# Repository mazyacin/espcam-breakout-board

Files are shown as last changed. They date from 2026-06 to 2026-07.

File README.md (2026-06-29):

# espcam-breakout-board
high-end ESP32-Cam breakout-board for IOT and monetering systems , so there has been a problem with the espcam and its the programming because it does not have a USB to UART converter so i am making a breakout board for it that solves that problem and adds more features like :tp5100 for charging ,MT3608 for 5v,3.3v,output, bme280 for IOT  also an IMU mpu6000 ,BMS( DW01A protection IC with 2 mosfets), 
it supports 4.2v batteries and cells any higher voltage will cut the power because the BMS is for 1s configuration, the charging is at 2A, bme temperature accuracy is ±0.5°C and humidity ±3%  Barometric Pressure ±1.0 hPa its set to i2c and its address is 0x76 or 0x77, mpu6000 is switched to i2c (cs pin is high) and address 0x69 accuracy Gyro: ±250 to ±2000 °/s accelerometer ±2g to ±16g internal tempurature sensor ±1°C

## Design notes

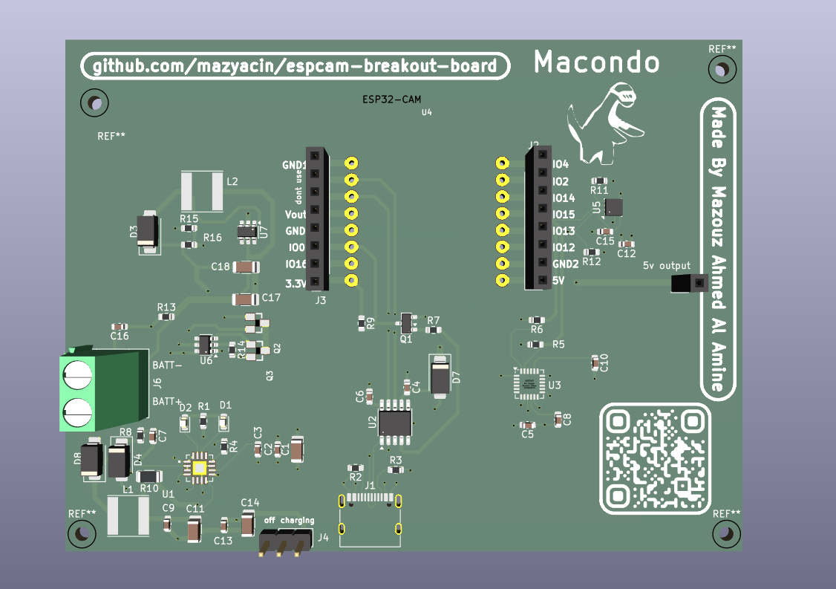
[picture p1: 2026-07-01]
espcam.PNG

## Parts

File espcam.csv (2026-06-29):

Reference | Qty | Value | DNP | Exclude from BOM | Exclude from Board | Footprint | Datasheet | LCSC
C1,C11,C14 | 3 | 10uf 16V |  |  |  | Capacitor_SMD:C_1206_3216Metric
C2,C3,C4,C5,C6,C8,C9,C12,C13,C15,C16 | 11 | 0.1uf 16V |  |  |  | Capacitor_SMD:C_0603_1608Metric
C7 | 1 | 0.1nf 16V |  |  |  | Capacitor_SMD:C_0603_1608Metric
C10 | 1 | 0.02uf 16V |  |  |  | Capacitor_SMD:C_0603_1608Metric
C17,C18 | 2 | 22uf 16v |  |  |  | Capacitor_SMD:C_1206_3216Metric
D1,D2 | 2 | LED |  |  |  | LED_SMD:LED_0603_1608Metric
D3,D4,D7,D8 | 4 | SS34 |  |  |  | Diode_SMD:D_SMA | https://www.vishay.com/docs/88751/ss32.pdf
J1 | 1 | USB_C_Receptacle_USB2.0_16P |  |  |  | Connector_USB:USB_C_Receptacle_G-Switch_GT-USB-7010ASV | https://www.usb.org/sites/default/files/documents/usb_type-c.zip
J2,J3 | 2 | Conn_01x08_Socket |  |  |  | Connector_PinSocket_2.54mm:PinSocket_1x08_P2.54mm_Vertical
J4 | 1 | Conn_01x03_Pin |  |  |  | Connector_PinHeader_2.54mm:PinHeader_1x03_P2.54mm_Vertical
L1 | 1 | 10uh |  |  |  | Inductor_SMD:L_Taiyo-Yuden_NR-60xx
L2 | 1 | 22uh |  |  |  | Inductor_SMD:L_Taiyo-Yuden_NR-60xx
Q1 | 1 | SS8050 |  |  |  | Package_TO_SOT_SMD:SOT-23 | http://www.secosgmbh.com/datasheet/products/SSMPTransistor/SOT-23/SS8050.pdf
Q2,Q3 | 2 | SI2302 |  |  |  | 65161:SOT23
R1,R14 | 2 | 1k ohm |  |  |  | Resistor_SMD:R_0603_1608Metric
R2,R3 | 2 | 5.1k ohm |  |  |  | Resistor_SMD:R_0603_1608Metric
R4 | 1 | 50k ohm |  |  |  | Resistor_SMD:R_0603_1608Metric
R5,R6,R11,R12 | 4 | 4.7k ohm |  |  |  | Resistor_SMD:R_0603_1608Metric
R7,R9 | 2 | 10k ohm |  |  |  | Resistor_SMD:R_0603_1608Metric
R8 | 1 | 3 ohm |  |  |  | Resistor_SMD:R_0603_1608Metric
R10 | 1 | 0.067 Ω |  |  |  | Resistor_SMD:R_1206_3216Metric
R13 | 1 | 100 ohm |  |  |  | Resistor_SMD:R_0603_1608Metric
R15 | 1 | 2.2k ohm |  |  |  | Resistor_SMD:R_0603_1608Metric
R16 | 1 | 16.13k ohm |  |  |  | Resistor_SMD:R_0603_1608Metric
U1 | 1 | TP5100 |  |  |  | TP5100:TP5100 | https://voltiq.ru/datasheets/TP5100-datashhet.pdf | C379389
U2 | 1 | CH340K |  |  |  | Package_SO:SSOP-10-1EP_3.9x4.9mm_P1mm_EP2.1x3.3mm | https://cdn.sparkfun.com/assets/5/0/a/8/5/CH340DS1.PDF | C968586
U3 | 1 | MPU-6000 |  |  |  | Sensor_Motion:InvenSense_QFN-24_4x4mm_P0.5mm | https://invensense.tdk.com/wp-content/uploads/2015/02/MPU-6000-Datasheet1.pdf
U4 | 1 | ESP32-CAM |  |  |  | espcam:ESP32-CAM | https://www.handsontec.com/dataspecs/module/ESP32-CAM.pdf,
U5 | 1 | BME280 |  |  |  | Package_LGA:Bosch_LGA-8_2.5x2.5mm_P0.65mm_ClockwisePinNumbering | https://www.bosch-sensortec.com/media/boschsensortec/downloads/datasheets/bst-bme280-ds002.pdf | C92489
U6 | 1 | DW01A |  |  |  | Package_TO_SOT_SMD:SOT-23-6 | https://hmsemi.com/downfile/DW01A.PDF | C11702
U7 | 1 | MT3608 |  |  |  | Package_TO_SOT_SMD:SOT-23-6 | https://www.olimex.com/Products/Breadboarding/BB-PWR-3608/resources/MT3608.pdf | C83247

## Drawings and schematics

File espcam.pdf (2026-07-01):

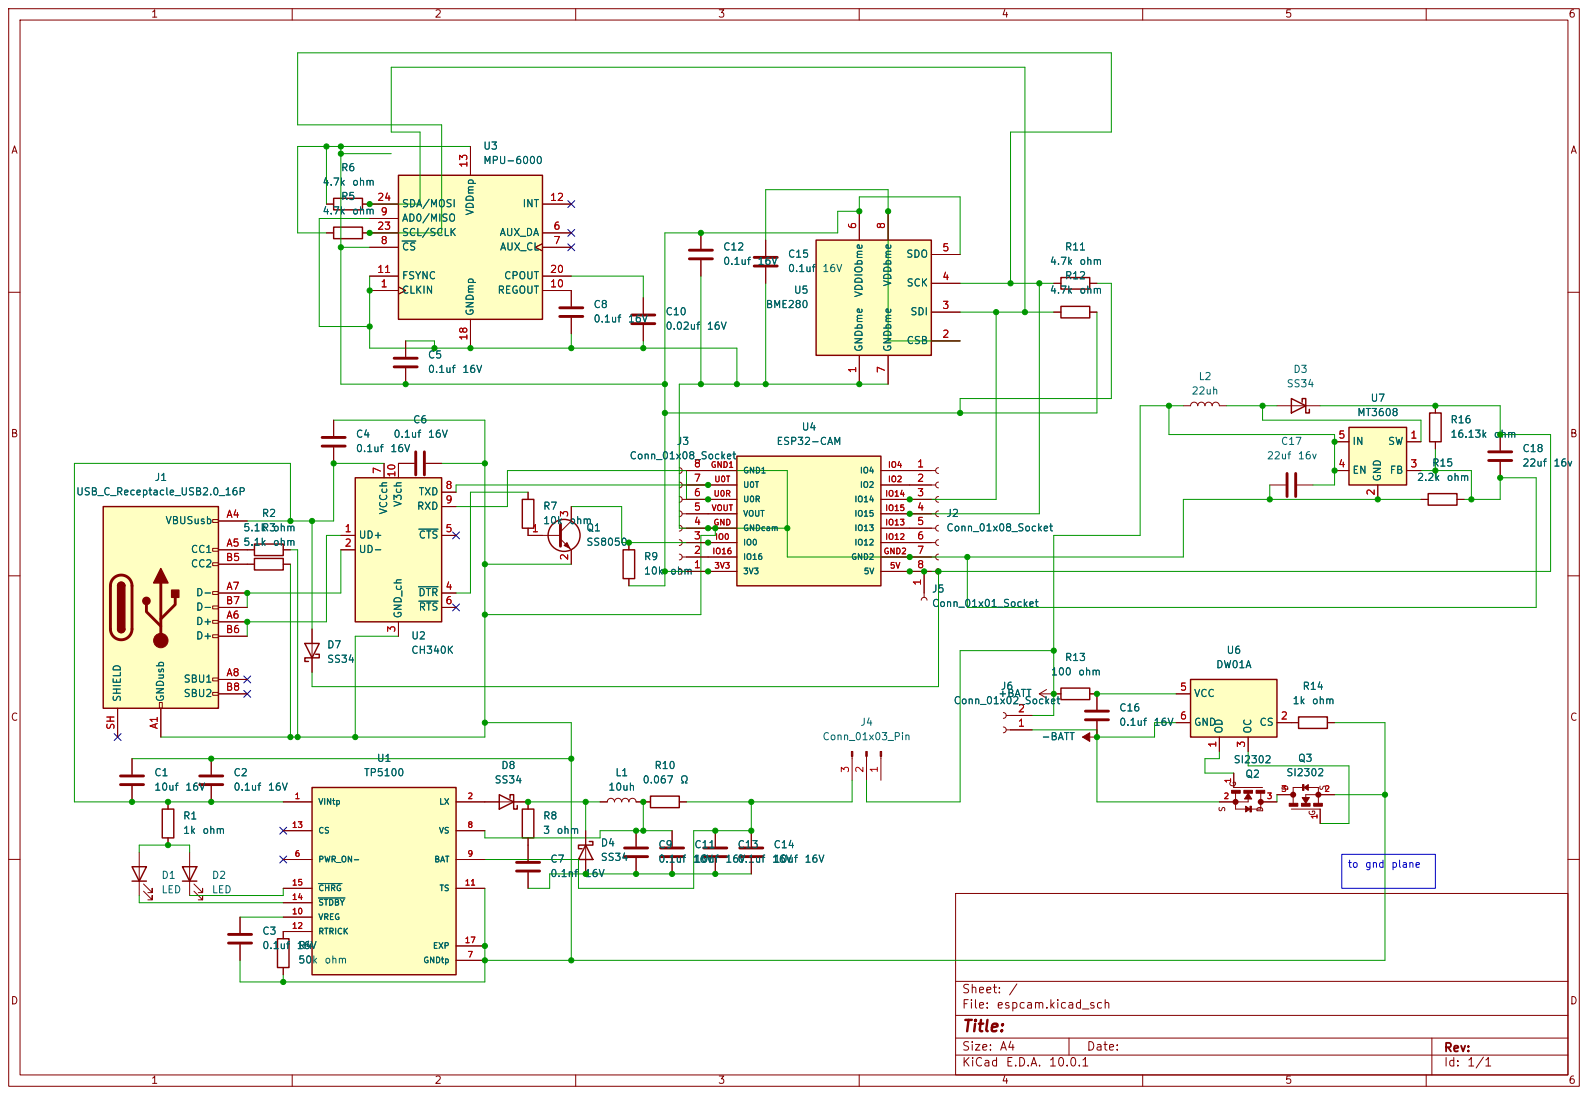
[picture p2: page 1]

J5Conn_01x01_Socket 1 U4

J3 Conn_01x08_Socket ESP32-CAM 1

Size: A4 | Rev:
KiCad E.D.A. 10.0.1 | Id: 1/1

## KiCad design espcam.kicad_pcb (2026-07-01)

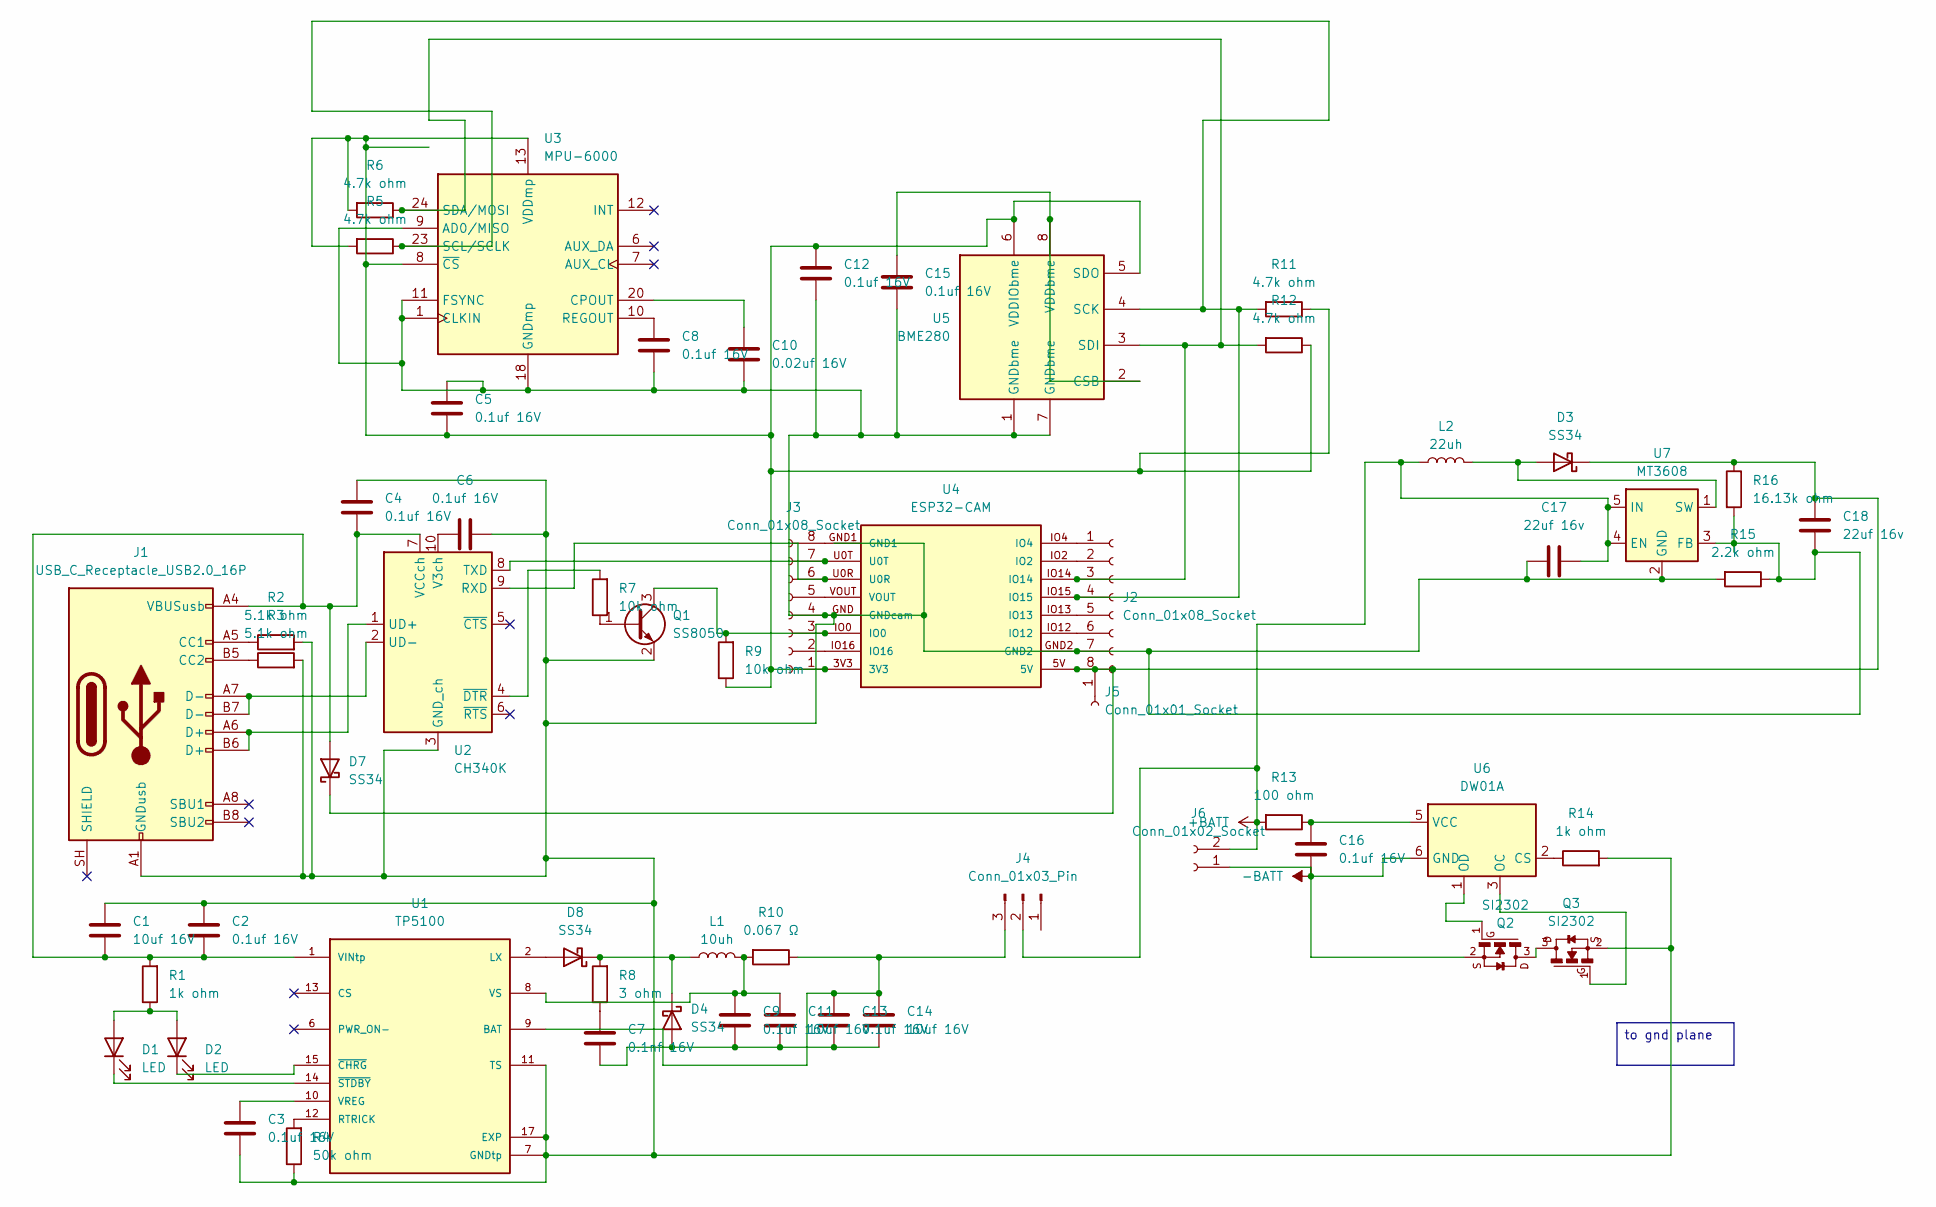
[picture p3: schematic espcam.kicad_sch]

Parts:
C1, C11, C14: 10uf 16V; C_1206_3216Metric
C2, C3, C4, C5, C6, C8, C9, C12, C13, C15, C16: 0.1uf 16V; C_0603_1608Metric
C7: 0.1nf 16V; C_0603_1608Metric
C10: 0.02uf 16V; C_0603_1608Metric
C17, C18: 22uf 16v; C_1206_3216Metric
D1, D2: LED; LED_0603_1608Metric
D3, D4, D7, D8: SS34; D_SMA
J1: USB_C_Receptacle_USB2.0_16P; USB_C_Receptacle_G-Switch_GT-USB-7010ASV
J2, J3: Conn_01x08_Socket; PinSocket_1x08_P2.54mm_Vertical
J4: Conn_01x03_Pin; PinHeader_1x03_P2.54mm_Vertical
J5: Conn_01x01_Socket; PinSocket_1x01_P2.54mm_Vertical
J6: Conn_01x02_Socket; TerminalBlock_Phoenix_MKDS-1,5-2-5.08_1x02_P5.08mm_Horizont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
L1: 10uh; L_Taiyo-Yuden_NR-60xx
L2: 22uh; L_Taiyo-Yuden_NR-60xx
Q1: SS8050; SOT-23
Q2, Q3: SI2302; SOT23
R1, R14: 1k ohm; R_0603_1608Metric
R2, R3: 5.1k ohm; R_0603_1608Metric
R4: 50k ohm; R_0603_1608Metric
R5, R6, R11, R12: 4.7k ohm; R_0603_1608Metric
R7, R9: 10k ohm; R_0603_1608Metric
R8: 3 ohm; R_0603_1608Metric
R10: 0.067 Ω; R_1206_3216Metric
R13: 100 ohm; R_0603_1608Metric
R15: 2.2k ohm; R_0603_1608Metric
R16: 16.13k ohm; R_0603_1608Metric
U1: TP5100; PARTREV 2.3; LCSC C379389
U2: CH340K; SSOP-10-1EP_3.9x4.9mm_P1mm_EP2.1x3.3mm; LCSC C968586
U3: MPU-6000; InvenSense_QFN-24_4x4mm_P0.5mm
U4: ESP32-CAM
U5: BME280; Bosch_LGA-8_2.5x2.5mm_P0.65mm_ClockwisePinNumbering; LCSC C92489
U6: DW01A; SOT-23-6; LCSC C11702
U7: MT3608; SOT-23-6; LCSC C83247

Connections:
+BATT: C17.2, J4.2, J6.2, L2.1, R13.2, U7.4 (EN), U7.5 (IN)
-BATT: C16.2, J6.1, Q2.2, U6.6 (GND)
unnamed: C7.1, R8.1
unnamed: D1.2 (A), D2.2 (A), R1.1
unnamed: D1.1 (K), U1.14 (~STDBY)
unnamed: D2.1 (K), U1.15 (~CHRG)
unnamed: D3.2 (A), L2.2, U7.1 (SW)
unnamed 7: C18.1, D3.1 (K), D7.1 (K), J2.8, J5.1, R16.1, U4.5V; also elsewhere on the board
unnamed: C7.2, C9.2, C11.2, C13.2, C14.2, D4.2 (A)
unnamed: D4.1 (K), D8.1 (K), L1.1, R8.2
unnamed: C1.2, C2.2, C4.2, D7.2 (A), J1.A4 (VBUSusb), J1.A9 (VBUS), J1.B4 (VBUS), J1.B9 (VBUS), R1.2, U1.1 (VINtp), U1.4 (VIN), U1.5 (VIN), U1.16 (VIN), U2.7 (VCCch)
unnamed: D8.2 (A), U1.2 (LX), U1.3 (LX)
unnamed: J1.A5 (CC1), R2.1
unnamed: J1.B5 (CC2), R3.1
unnamed: C1.1, C2.1, C3.2, C4.1, C5.1, C6.2, C8.2, C10.2, C12.2, C15.2, C17.1, C18.2, J1.A1 (GNDusb), J1.A12 (GND), J1.B1 (GND), J1.B12 (GND), J2.7, J3.4, Q1.2 (E), Q3.2, R2.2, R3.2, R4.1, R14.2, R15.1, R15.2, R16.2, U1.7 (GNDtp), U1.11 (TS), U1.17 (EXP), U2.3 (GND_ch), U2.11 (GND), U3.1 (CLKIN), U3.9 (AD0/MISO), U3.11 (FSYNC), U3.18 (GNDmp), U4.GND (GNDcam), U4.GND2, U5.1 (GNDbme), U5.7 (GNDbme), U7.2 (GND), U7.3 (FB)
unnamed: J2.1, U4.IO4
unnamed: J2.2, U4.IO2
unnamed: J2.3, R6.1, R12.2, U3.24 (SDA/MOSI), U4.IO14, U5.3 (SDI)
unnamed: J2.4, R5.1, R11.2, U3.23 (SCL/SCLK), U4.IO15, U5.4 (SCK)
unnamed: J2.5, U4.IO13
unnamed: J2.6, U4.IO12
unnamed: C5.2, C12.1, J3.1, R5.2, R6.2, R9.1, R11.1, R12.1, U3.8 (~CS), U3.13 (VDDmp), U4.3V3, U5.5 (SDO), U5.6 (VDDIObme)
unnamed: J3.2, U4.IO16
unnamed: J3.3, Q1.3 (C), R9.2, U4.IO0
unnamed: J3.5, U4.VOUT
unnamed: J3.6, U2.9 (RXD), U4.U0R
unnamed: J3.7, U2.8 (TXD), U4.U0T
unnamed: J3.8, U4.GND1
unnamed: C13.1, C14.1, J4.3, R10.1, U1.9 (BAT)
unnamed: Q1.1 (B), R7.1
unnamed: Q2.3, Q3.3
unnamed: R4.2, U1.12 (RTRICK)
unnamed: C3.1, U1.10 (VREG)
unnamed: C9.1, C11.1, L1.2, R10.2, U1.8 (VS)
unnamed: J1.A6 (D+), J1.B6 (D+), U2.1 (UD+)
unnamed: J1.A7 (D-), J1.B7 (D-), U2.2 (UD-)
unnamed: C6.1, U2.10 (V3ch)
unnamed: R7.2, U2.4 (~DTR)
unnamed: C10.1, U3.20 (CPOUT)
unnamed: C8.1, U3.10 (REGOUT)
unnamed: C15.1, U5.2 (CSB), U5.8 (VDDbme)
unnamed: R14.1, U6.2 (CS)
unnamed: Q3.1, U6.3 (OC)
unnamed: Q2.1, U6.1 (OD)
unnamed: C16.1, R13.1, U6.5 (VCC)

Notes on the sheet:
to gnd plane

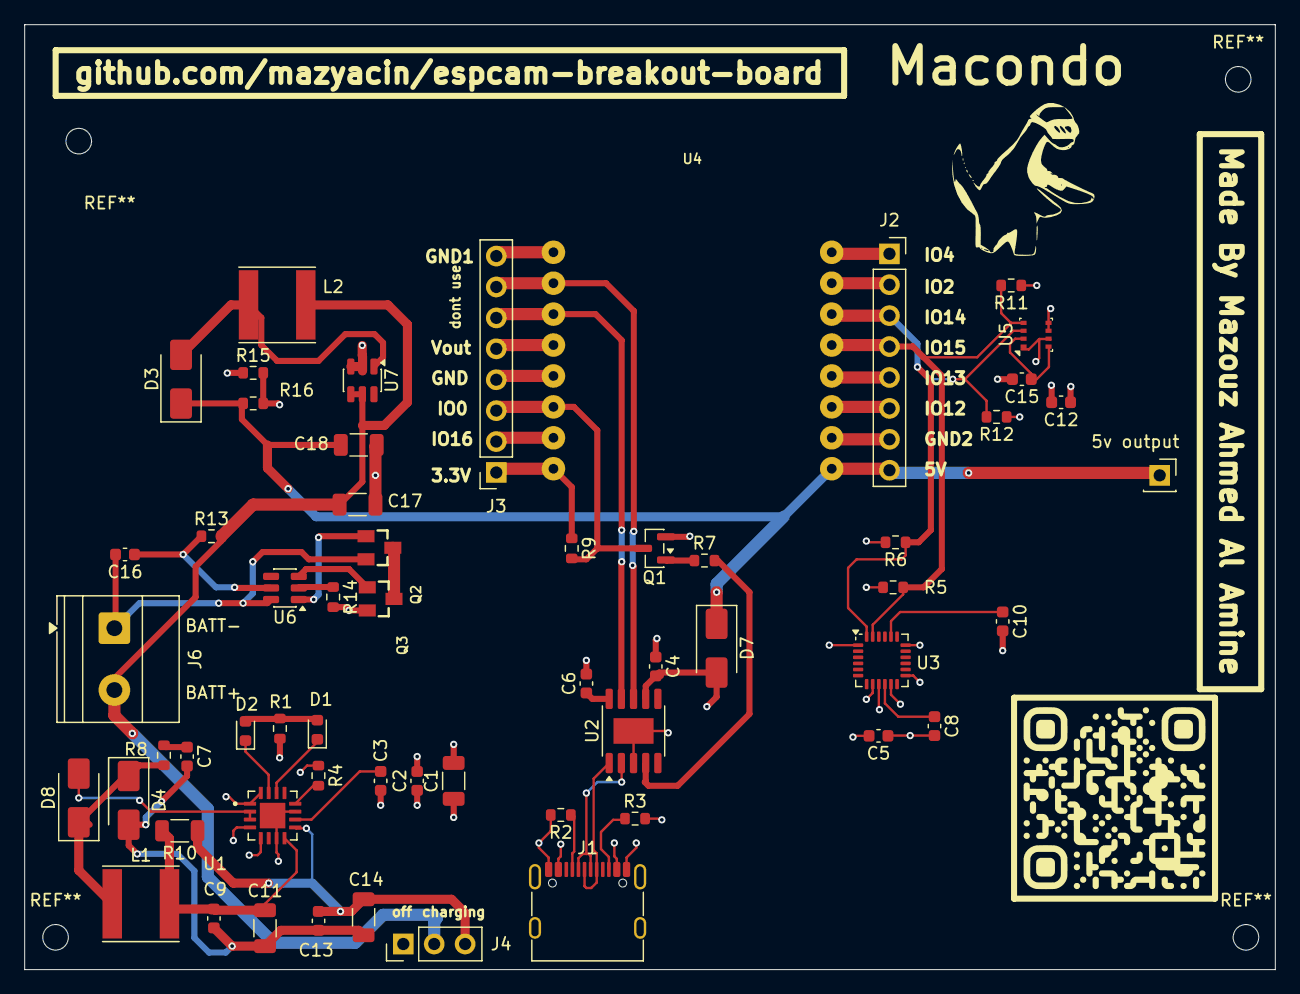
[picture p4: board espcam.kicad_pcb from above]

Board: 4 copper layers, 102.7 x 77.6 mm, 58 parts (0 on the bottom side), 45 nets.

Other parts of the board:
5v output: Conn_01x01_Socket; PinSocket_1x01_P2.54mm_Vertical

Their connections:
unnamed 7: 5v output.1 (Pin_1_1); also elsewhere on the board
